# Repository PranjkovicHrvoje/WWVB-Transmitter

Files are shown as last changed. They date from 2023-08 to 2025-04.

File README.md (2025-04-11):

# WWVB-Transmitter

WWVB transmitter made using SparkFun Pro Micro and Wemos D1 mini Lite.

Wemos D1 mini Lite connects to a WiFi network and retrieves the current time using NTP. It sends it to SparkFun Pro Micro which emmits the signal in the right format.

Pro Micro code is a modified version of https://github.com/micooke/WWVB.

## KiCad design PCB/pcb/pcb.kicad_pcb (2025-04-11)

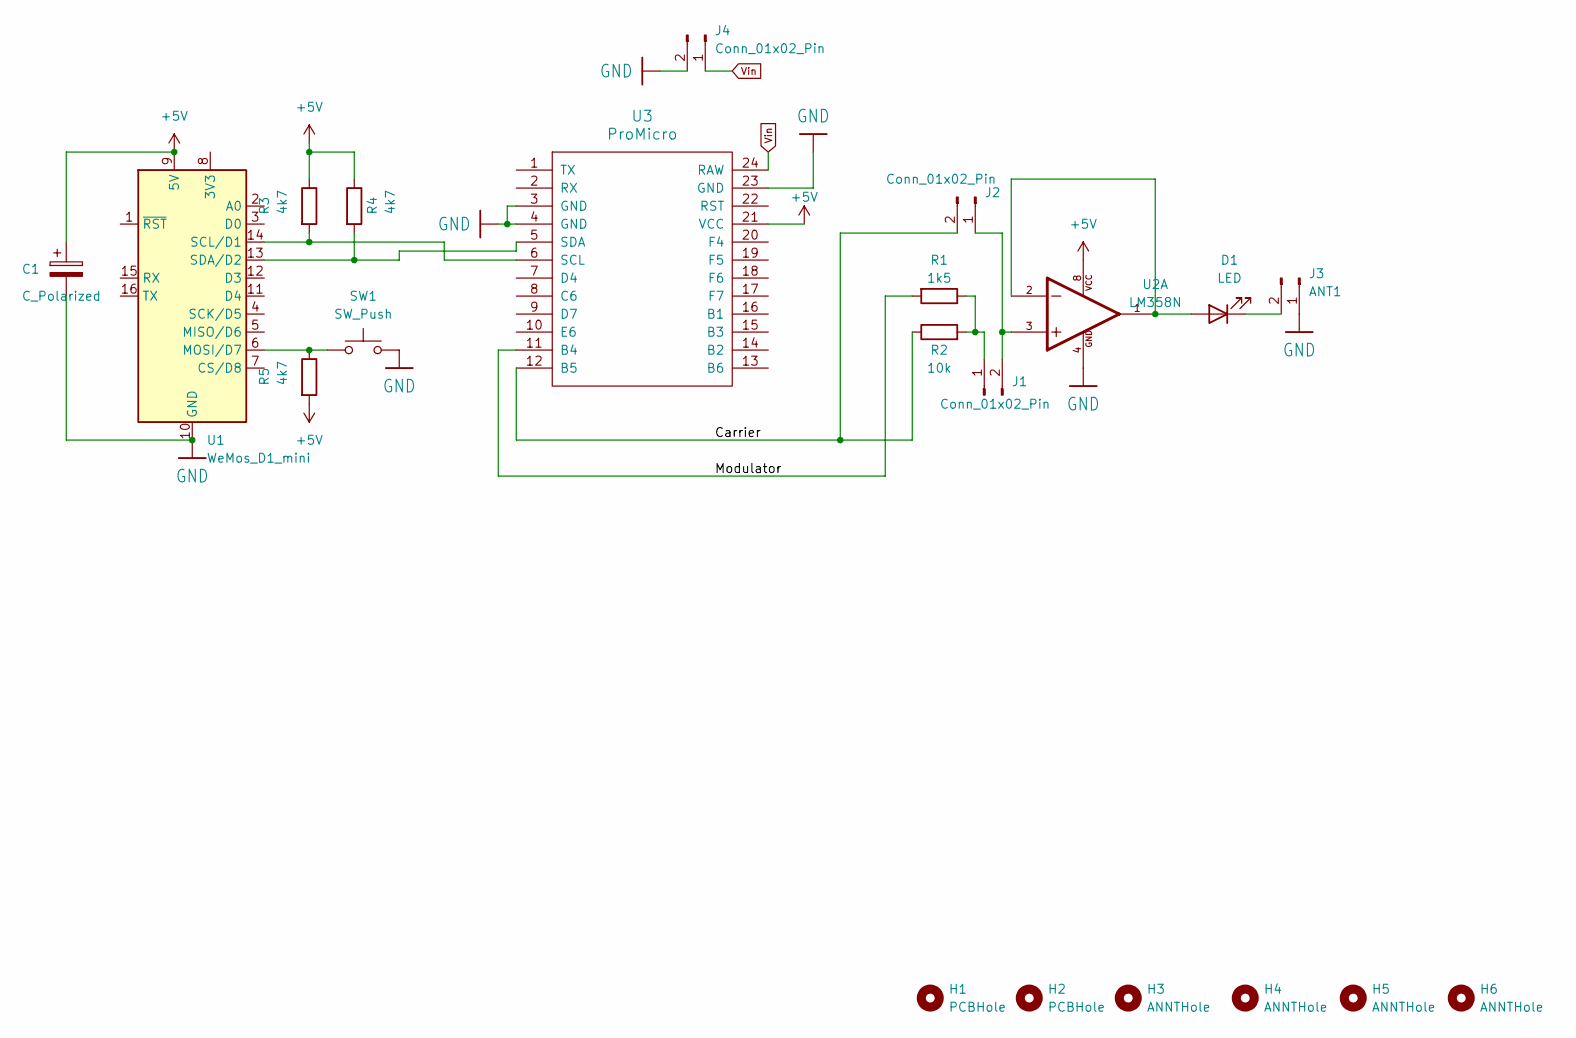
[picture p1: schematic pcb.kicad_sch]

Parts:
C1: C_Polarized; CP_EIA-3528-12_Kemet-T_Pad1.50x2.35mm_HandSolder
D1: LED; LED_D5.0mm
H1, H2: PCBHole; MountingHole_2.2mm_M2
H3, H4, H5, H6: ANNTHole; MountingHole_2.5mm
J1, J2, J4: Conn_01x02_Pin; PinHeader_1x02_P2.54mm_Vertical
J3: ANT1; PinHeader_1x02_P2.54mm_Vertical
R1: 1k5; R_0603_1608Metric
R2: 10k; R_0603_1608Metric
R3, R4, R5: 4k7; R_0603_1608Metric
SW1: SW_Push; SW_PUSH-12mm
U1: WeMos_D1_mini; WEMOS_D1_mini_light
U2: LM358N; DIP762W46P254L960H508Q8; PARTREV 1.0.3
U3: ProMicro

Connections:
+5V: C1.1, R3.1, R4.1, R5.2, U1.9 (5V), U2.8, U3.21 (VCC)
/Carrier: J2.2, R2.1, U3.12 (B5)
/Modulator: R1.2, U3.11 (B4)
GND: C1.2, J3.1, J4.2, SW1.2, U1.10 (GND), U2.4, U3.3 (GND), U3.4 (GND), U3.23 (GND)
unnamed: D1.2 (A), U2.1, U2.2
unnamed: D1.1 (K), J3.2
unnamed: J1.1, R1.1, R2.2
unnamed: J1.2, J2.1, U2.3
unnamed: R5.1, SW1.1, U1.6 (MOSI/D7)
unnamed: R3.2, U1.14 (SCL/D1), U3.6 (SCL)
unnamed: R4.2, U1.13 (SDA/D2), U3.5 (SDA)
Vin: J4.1, U3.24 (RAW)

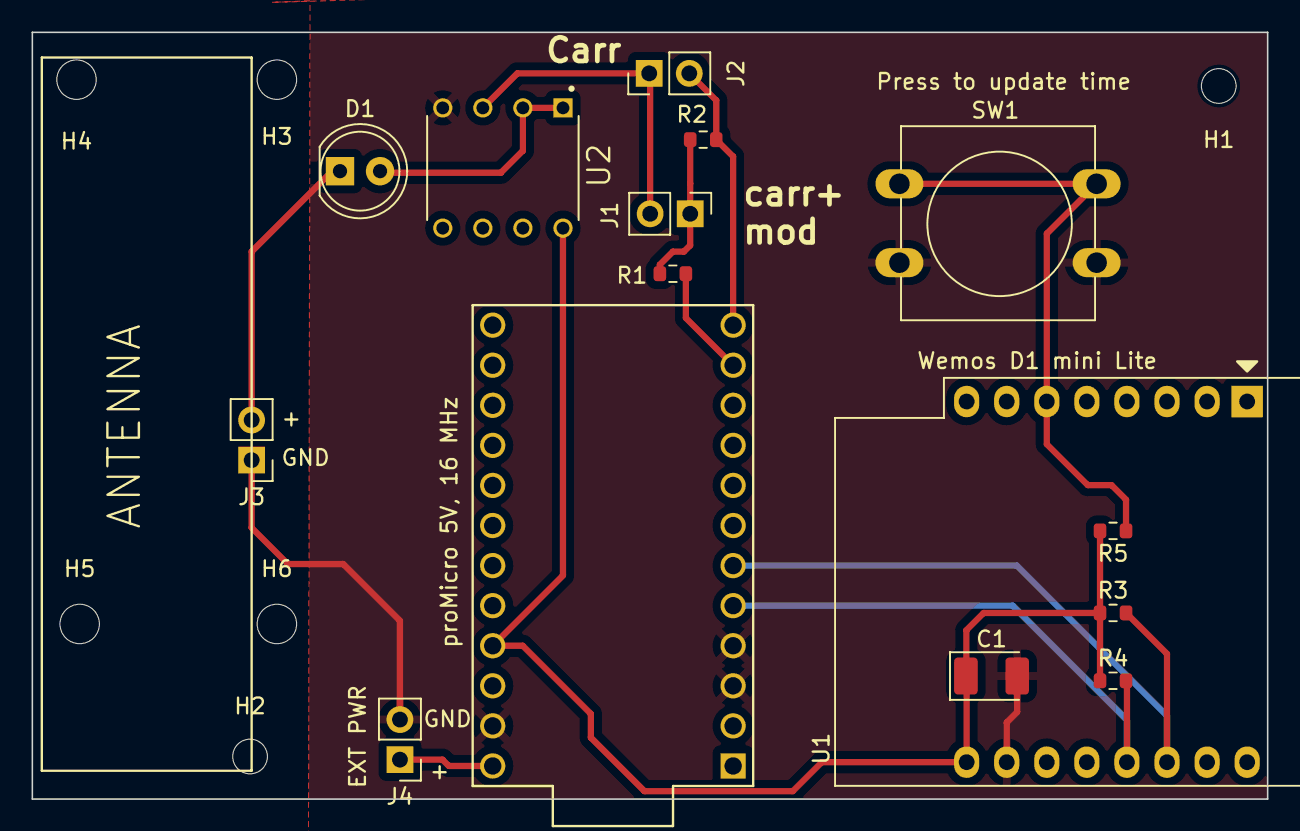
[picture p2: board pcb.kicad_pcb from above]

Board: 2 copper layers, 78.3 x 48.6 mm, 21 parts (0 on the bottom side), 12 nets.

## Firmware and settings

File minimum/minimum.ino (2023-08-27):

//ATtiny85
//                     +-\/-+
//            RST PB5 1|*   |8 VCC
//                PB3 2|    |7 PB2
//WWVB ANTENNA <= PB4 3|    |6 PB1
//                GND 4|    |5 PB0
//                     +----+
//
//Arduino Nano
//       +----+=====+----+
//       |    | USB |    |
// SCK 13| D13+-----+D12 |12 MISO
//       |3V3        D11~|11 MOSI
//       |Vref       D10~|10 SS
//     14| A0/D14     D9~|9 => WWVB ANTENNA
//     15| A1/D15     D8 |8
//     16| A2/D16     D7 |7
//     17| A3/D17     D6~|6
// SDA 18| A4/D18     D5~|5
// SCL 19| A5/D19     D4 |4
//     20| A6         D3~|3 INT1
//     21| A7         D2 |2 INT0
//       | 5V        GND |
//       | RST       RST |
//       | GND       TX1 |0
//       | Vin       RX1 |1
//       |  5V MOSI GND  |
//       |   [ ][ ][ ]   |
//       |   [*][ ][ ]   |
//       | MISO SCK RST  |
//       +---------------+
//
//Arduino Micro
//       +--------+=====+---------+
//       |        | USB |         |
// SCK 13| D13    +-----+     D12 |12 MISO
//       |3V3                 D11~|11 MOSI
//       |Vref                D10~|10 SS
//     14| A0/D14              D9~|9 => WWVB ANTENNA
//     15| A1/D15              D8 |8
//     16| A2/D16              D7 |7
//     17| A3/D17              D6~|6
// SDA 18| A4/D18              D5~|5
// SCL 19| A5/D19              D4 |4
//     20| A6                  D3~|3 INT1
//     21| A7                  D2 |2 INT0
//       | 5V                 GND |
//       | RST                RST |
//       | GND                TX1 |0
//       | Vin                RX1 |1
//       |MISO MISO[*][ ]VCC    SS|
//       |SCK   SCK[ ][ ]MOSI MOSI|
//       |      RST[ ][ ]GND      |
//       +------------------------+
//
//Sparkfun Pro Micro
//                  +----+=====+----+
//                  |[J1]| USB |    |
//                 1| TXO+-----+RAW |
//                 0| RXI       GND |
//                  | GND       RST |
//                  | GND       VCC |
//             SDA 2| D2         A3 |21
//             SCL 3|~D3         A2 |20
//                 4| D4         A1 |19
//                 5|~D5         A0 |18
//                 6|~D6        D15 |15 SCK
//                 7| D7        D14 |14 MISO
//                 8| D8        D16 |16 MOSI
//WWVB ANTENNA  <= 9|~D9        D10~|10
//                  +---------------+

/*
Recommended debug setup
Use a RC (low-pass) filter to view the message (p1) as well as the modulated carrier (p0)

T = RC = 1/(2*pi*fc)
where;
T: Time constant
fc: cutoff frequency

for: R = 110 ohm, C = 1uF
fc = 1/(2*pi*RC) = 1.45kHz (the carrier is 60kHz, the modulation is about 1 to 5 Hz)

WWVB_OUT |--(p0)--[110R]--(p1)--[1uF]--|GND

-----------+-----------+-----------------
Chip       | #define   | WWVB_OUT
-----------+-----------+-----------------
ATtiny85   |  USE_OC1A | D1 / PB1 (pin 6)
ATtiny85   | *USE_OC1B | D4 / PB4 (pin 3)
-----------+-----------+-----------------
ATmega32u4 | *USE_OC1A | D9
ATmega32u4 |  USE_OC1B | D10
-----------+-----------+-----------------
ATmega328p | *USE_OC1A | D9
ATmega328p |  USE_OC1B | D10
-----------+-----------+-----------------

* Default setup
*/



#include <Arduino.h>
#include <avr/interrupt.h>
//#define WWVB_PAM

#if defined(__AVR_ATtiny25__) | defined(__AVR_ATtiny45__) | defined(__AVR_ATtiny85__)
#define _DEBUG 0
#elif defined(__AVR_ATmega16U4__) | defined(__AVR_ATmega32U4__)
#define _DEBUG 1
#else
#define _DEBUG 1
#endif

/*
_DEBUG == 0: Set wwvb time to the compile time, use the wwvb interrupt, blink the led
_DEBUG == 1: Set wwvb time to the compile time, use the wwvb interrupt, blink the led, serial output
*/

#if defined(__AVR_ATtiny25__) | defined(__AVR_ATtiny45__) | defined(__AVR_ATtiny85__)
unsigned char LED_PIN = 1; // Use the Tx LED on the digistump
#elif defined(__AVR_ATmega16U4__) | defined(__AVR_ATmega32U4__)
unsigned char LED_PIN = SS;
#elif defined(__AVR_ATmega168__) | defined(__AVR_ATmega168P__) | defined(__AVR_ATmega328P__)
unsigned char LED_PIN = 13;
#elif defined(__STM32F1__)
unsigned char LED_PIN = PB13;
#else
unsigned char LED_PIN = 13;
#endif

uint8_t mins = 0;
uint16_t LED_FAST = 100;
uint16_t SLOW_DELAY = 1000;
bool LED_TOGGLE = false;
uint32_t t0;


#define REQUIRE_TIMEDATESTRING 1

#include "TimeDateTools.h" // include before wwvb.h AND/OR ATtinyGPS.h
#include "wwvb.h" // include before ATtinyGPS.h

#include <Wire.h>
#include <Time.h>

wwvb wwvb_tx;

// The ISR sets the PWM pulse width to correspond with the WWVB bit
ISR(TIMER1_OVF_vect)
{
  wwvb_tx.interrupt_routine();
}


unsigned long T = 0;
int flag = 0;
time_t epochTime;
struct tm *current_time;

void setup()
{
  wwvb_tx.setup();

  Serial.begin(9600);

  Wire.begin(27);                // join I2C bus with address #8
  Wire.onReceive(receiveEvent); // register event
  pinMode(LED_PIN, OUTPUT);
  
  Serial.println();  
}
void loop()
{
}

void receiveEvent(int howMany) {
  byte a, b, c, d;
  a = Wire.read();
  b = Wire.read();
  c = Wire.read();
  d = Wire.read();
  
  T = a;
  T = (T << 8) | b;
  T = (T << 8) | c;
  T = (T << 8) | d;

  epochTime = T;
  current_time = localtime(&epochTime);

  Serial.println(T);
    uint8_t hh = current_time->tm_hour + 2;
    uint8_t mm = current_time->tm_min;
    uint8_t ss = current_time->tm_sec;
    uint8_t DD = current_time->tm_mday + 1;
    uint8_t MM = current_time->tm_mon + 1;
    uint8_t YY = current_time->tm_year - 230;

    wwvb_tx.set_time(hh, mm, DD, MM, YY, 0);
    wwvb_tx.debug_time();
    wwvb_tx.start(); // Thats it
}

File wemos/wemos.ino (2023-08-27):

#include <ESP8266WiFi.h>
#include <NTPClient.h>
#include <WiFiUdp.h>
#include <Wire.h>
#define DEBUG


unsigned long T = 0;

// Network credentials
const char* ssid = "Ejovrh";
const char* password = "12345679";


WiFiUDP ntpUDP;
NTPClient timeClient(ntpUDP, "hr.pool.ntp.org");


void setup() {
  Serial.begin(9600);
  pinMode(BUILTIN_LED, OUTPUT);
  pinMode(13, INPUT_PULLUP);

  //Connecting to WiFi
  WiFi.hostname("Name");
  WiFi.begin(ssid, password);

  while (WiFi.status() != WL_CONNECTED) {
    digitalWrite(BUILTIN_LED, HIGH);
    delay(500);
    Serial.print(".");
  }
  digitalWrite(BUILTIN_LED, LOW);
  Wire.begin();
  timeClient.begin();
}

void loop() {
  if (digitalRead(13) == LOW) {
    Serial.println("Started");
    timeClient.update();
    T = timeClient.getEpochTime();
    Wire.beginTransmission(27);

    byte a, b, c, d;
    a = (T >> 24) & 0xFF;
    b = (T >> 16) & 0xFF;
    c = (T >> 8) & 0xFF;
    d = T & 0xFF;
    Wire.write(a);
    Wire.write(b);
    Wire.write(c);
    Wire.write(d);

    Wire.endTransmission();

    Serial.println(T);
    Serial.println("Sent");

    delay(1000);
    T = 0;
  }  
}
